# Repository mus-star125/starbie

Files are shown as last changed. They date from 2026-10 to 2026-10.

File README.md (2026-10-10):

# starbie

I made a starbie keychian - thats a bit vague. Basically a simpler version of the popular "starboy" keychain. its the first project we made in half-life and the first hardware - project I have ever made!

Before I even got to the instructions i ran into my first problem: downloading KiCad. Now this step is really easy on windows or mac but unfortunately I don't have those and had to use my chrome book. The process of downloading KiCad on Chromebook is different and was completely new to me. I had to start by installing Linux - which is a tiny computer in my computer- I assigned it about 10GB and had to code- download KiCad using terminal  - which is according to google: "a command-line interface application used to run text-based commands, access a Linux development environment, or perform system diagnostics."- After about an hour of trying to figure the code out i finally got it to install but then i realised 10GB was not enough so I moved it up to 25GB (That work wayy better)

**Some pics of me trying to figure linux and terminal out:**

Screenshot 2026-10-05 7 14 41 PM
Screenshot 2026-10-05 7 33 18 PM
Screenshot 2026-10-05 7 37 12 PM

for some reason it was a lot more tedious then it should have been. I think this process itself took me like 2 hours (which i wasn't able to count in my half life hours)  

Lessons learnt: **This wasn't as simple as I thought it would be** 
but i also learned that Linux was a mini computer system on mine and learned how to operate it :)

**CHALLENGE 2: Navigating KiCad**
I just could not understand the preferences and after downloading the "week one guide"zip I couldn't figure out how to put it onto KiCad, So my YouTube search started. I looked for videos and videos and ended up turning to slack, this was my last choice because I have a hard time turning for help since i enjoy figuring things out on my own and someone (i cant remember the @) sent a really helpful video which finally helped me understand it. So, i finally opened a schematic file and started searching for all the parts- honestly I'm still figuring out what each part does and how it all works but whatever info i find out Im going to add in here later.

I messed up again, I couldn't find the imported parts like the XIAO-ESP32-C3-SMD (which was the BRAIN of this project) at this point I was quite frustrated; whenever something seemed like it was going well another challenge came up... but I wasn't a quitter and by some playing around they appeared in my library (Again i had to share these files with Linux and it was making everything more difficult) but looking back at it I enjoy this process, when it all clicks all that frustration and hard work feels worth it!  

image0 (4)

I made my schematic file and I was soo proud of the result!
Schematic Edit: 



 I couldn't believe I the designed it all on my own (with the instructions and youtube <3). Finishing the schematic editor took me about 3.5 hours and I was really happy with the result!

**Making the PCB: Not as challenging as the Schematic :D**
I was really excited seeing my schematic becoming a model! It was kind of intimidating with the hundreds of tools in the PCB editor, but it ended up working out.

I started by organising my parts like the guide, i then went on the edge cut layer to make the star outline, this was probably the easiest part out of the project :) then i connected the wires. I was kind of worried because i did not have the same wiring as the guide, but with some research i realised that it will work the same. Then I added funny text and cute pictures on the board (Like the cute balloon dog). In all, the PCB was a much more enjoyable process than the schematic, but it still took me some time to get it done.About 6.5 hours in total. I finally downloaded the Gerber files and uploaded them onto my github

here is how it turned out: 

image1 (3)

**finally: The firmware**
The firmware was the quickest and easiest process out of the whole project; i used the beginner guide and made my own character. Making my sorite was difficult since i could only use black and white but I'm really proud with how it turned out. I have some things in mind that i want to experiment with but am waiting for the hardware for that.

This took me about 2 hours!

Then it occured to me that i wasn't a big fan of my star shape so I had to go back into the PCB editor to fix it, which was tedious because i had to re-download and re-upload my gerber files onto github and JLCPCB

Here is my Sprite:

sprite

Overall, this was a really enjoyable project and a good way to test my patience ;) It took me alot of time and my chromebook kept crashing out but I enjoyed it all and thank half-life for making this beginner friendly! I now have to figure out the funding and what to buy and how to make so I stay in the 30$

**week 1: SUCCESS!**

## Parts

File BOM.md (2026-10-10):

# Starbie – bill of materials

<!-- Generated by Half Life from project cmuvvz5y2026b01oscevl8rsv. Edits here are overwritten on the next sync. -->
<!-- Generated: 2026-10-10T16:02:22.605Z -->

> [!NOTE]
> This parts list is mirrored from [Half Life](https://halflife.hackclub.com). Editing it here will not change the platform's copy, and the next sync overwrites this file.

| Week | Tier | Parts funding |
| --- | --- | --- |
| Week 1 | Tier 1 | $30.00 |

| Part | What it's for | Qty | Unit | Total | Vendor |
| --- | --- | --- | --- | --- | --- |
| [PCB](https://cart.jlcpcb.com/shopcart/cart/) | holds electronic parts in place and connects them | 1 | $2.80 | $2.80 | [JLCPCB](https://cart.jlcpcb.com/shopcart/cart/) |
| [OLED Display](https://www.aliexpress.com/item/1005013248598840.html?mp=1) | where the action is going to happen | 1 | $3.87 | $3.87 | [AliExpress](https://www.aliexpress.com/item/1005013248598840.html?mp=1) |
| [Push buttons](https://www.aliexpress.com/item/1005006046180384.html?mp=1) | for changing option on the starbie | 1 | $4.46 | $4.46 | [AliExpress](https://www.aliexpress.com/item/1005006046180384.html?mp=1) |
| [PIn Header](https://www.aliexpress.com/item/1005007528068254.html?mp=1) | transmit data | 1 | $1.82 | $1.82 | [AliExpress](https://www.aliexpress.com/item/1005007528068254.html?mp=1) |
| **Parts subtotal** | — | — | — | **$12.95** | — |
| **Tax & shipping** | — | — | — | **$9.50** | — |
| **Total** | — | — | — | **$22.45** | — |

$7.55 left of the tier's funding.

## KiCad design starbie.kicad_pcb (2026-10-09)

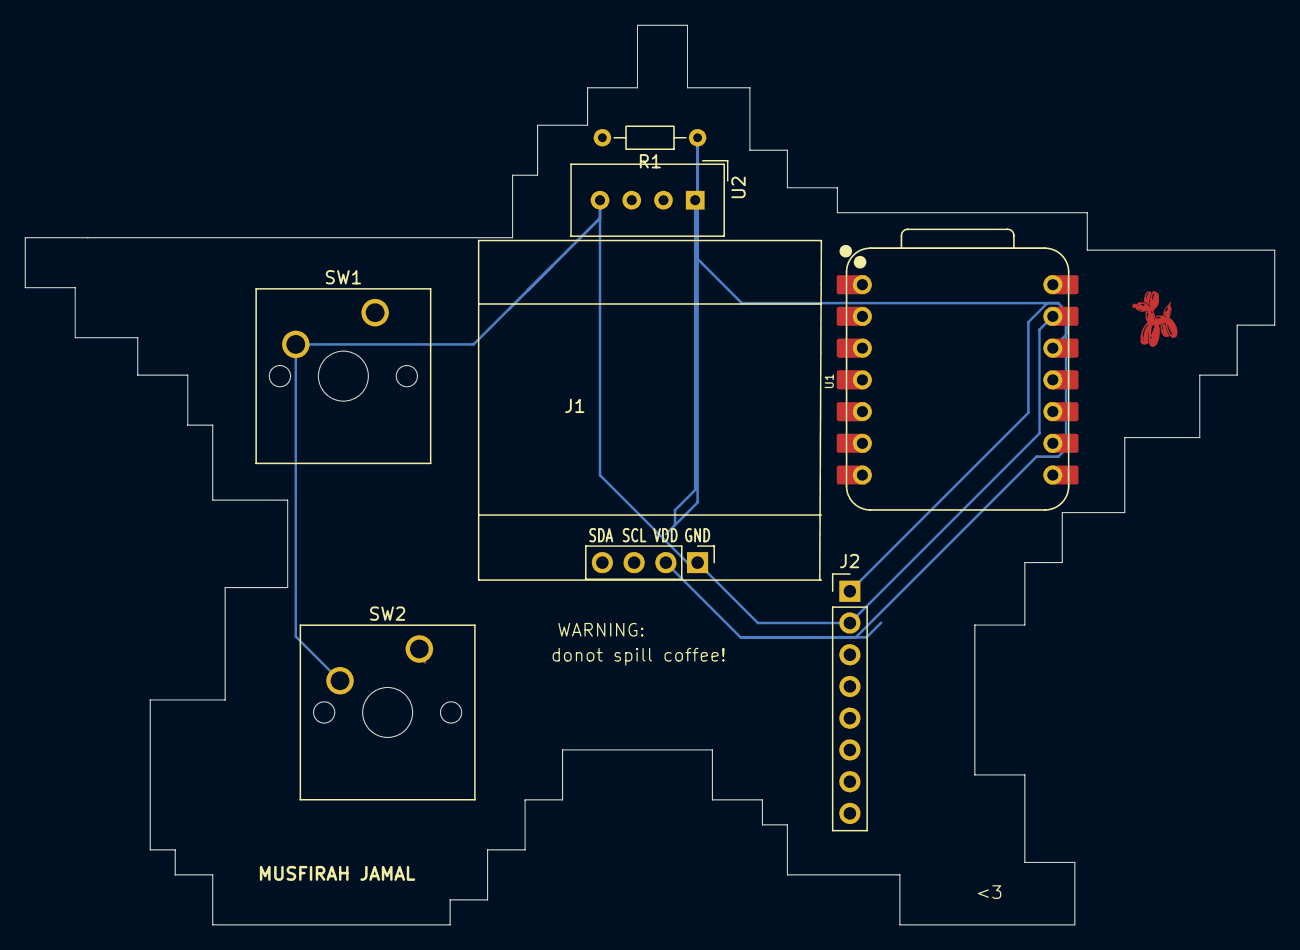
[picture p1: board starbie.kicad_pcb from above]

Board: 2 copper layers, 100.0 x 72.0 mm, 7 parts (0 on the bottom side), 2 nets.

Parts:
J1: Conn_01x04_Pin; Display_128x64_096_I2C
J2: Conn_01x08_Pin; PinHeader_1x08_P2.54mm_Vertical
R1: 10K; R_Axial_DIN0204_L3.6mm_D1.6mm_P7.62mm_Horizontal
SW1, SW2: SW_Push; SW_Cherry_MX_1.00u_PCB
U1: XIAO-ESP32-C3-SMD; XIAO-ESP32-C6-DIP
U2: DHT11; Aosong_DHT11_5.5x12.0_P2.54mm

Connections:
+3.3V: J1.2, J2.1, R1.1, U1.12 (3V3_OUT), U2.1 (VDD)
GND: J1.1, J2.2, SW1.2 (2_2), SW2.2 (2_2), U1.13 (GND), U2.4 (GND)

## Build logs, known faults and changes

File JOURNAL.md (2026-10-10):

# Starbie – devlog

<!-- Generated by Half Life from project cmuvvz5y2026b01oscevl8rsv. Edits here are overwritten on the next sync. -->
<!-- Generated: 2026-10-10T05:56:46.244Z -->

> [!NOTE]
> This devlog is mirrored from [Half Life](https://halflife.hackclub.com). Editing it here will not change the platform's copy, and the next sync overwrites this file.

> A tiny motion-controlled digital pet, basically a desktop Tamagotchi. Totally not a Starboy.

| Week | Tier | Hours logged | Entries |
| --- | --- | --- | --- |
| Week 1 | Tier 1 | 13.5h | 5 |

## Contents

1. [2026-10-06 – Today I struggled, I downloaded KiCad and got straight to work! I finished the Schimetic Editor file and this process took me about 3 h! this does not include the videos i watched and the millions of](#2026-10-06-today-i-struggled-i-downloaded-kicad-and-got-stra)
2. [2026-10-06 – Today was day 2 for hack club, and it was wayy easier then yesterday. I finished up my schematic editor and actually started the PCB, I enjoyed graphing the star but it was quite difficult I also move](#2026-10-06-today-was-day-2-for-hack-club-and-it-was-wayy-eas)
3. [2026-10-07 – today i wired, fixed the thousands of errors (started with 42) i had and added cute little stickers and photos on my pcb. safe to say I just need to add a few more details before im finally done. I sa](#2026-10-07-today-i-wired-fixed-the-thousands-of-errors-start)
4. [2026-10-08 – Today was a lighter day, i mostly spent today designing my PCB since im done (and did it wrong yesterday), and rechecking for errors I also learned how to use image converter which kinda confused me a](#2026-10-08-today-was-a-lighter-day-i-mostly-spent-today-desi)
5. [2026-10-10 – I finally finished up my project today. Im done with the firmware aswell! I really enjoyed making my sorite even though it took some time. the code was pretty easy since i used the beginner pack and j](#2026-10-10-i-finally-finished-up-my-project-today-im-done-wi)

## Design

### 2026-10-06 – Today I struggled, I downloaded KiCad and got straight to work! I finished the Schimetic Editor file and this process took me about 3 h! this does not include the videos i watched and the millions of

**3h**

Today I struggled, I downloaded KiCad and got straight to work! I finished the Schimetic Editor file and this process took me about 3 h! this does not include the videos i watched and the millions of websites i opened. My favoirtie part were the keyboard shortcuts, w for wire q for x ect







### 2026-10-06 – Today was day 2 for hack club, and it was wayy easier then yesterday. I finished up my schematic editor and actually started the PCB, I enjoyed graphing the star but it was quite difficult I also move

**2.5h**

Today was day 2 for hack club, and it was wayy easier then yesterday. I finished up my schematic editor and actually started the PCB, I enjoyed graphing the star but it was quite difficult I also moved some of the pieces around to match the guide



. I must say im really proud with how it turned out! Day 2, success!!



Screenshot 2026-10-06 8.34.33 PM

### 2026-10-07 – today i wired, fixed the thousands of errors (started with 42) i had and added cute little stickers and photos on my pcb. safe to say I just need to add a few more details before im finally done. I sa

**4h**

today i wired, fixed the thousands of errors (started with 42) i had and added cute little stickers and photos on my pcb. safe to say I just need to add a few more details before im finally done. I saw the 3D model and its so exciting seeing my work come to life!









### 2026-10-08 – Today was a lighter day, i mostly spent today designing my PCB since im done (and did it wrong yesterday), and rechecking for errors I also learned how to use image converter which kinda confused me a

**2h**

Today was a lighter day, i mostly spent today designing my PCB since im done (and did it wrong yesterday), and rechecking for errors I also learned how to use image converter which kinda confused me at first but by some playing around i got the hang of it!
Tonight im going to download arduine IDE, excited to start the firmware tomorrow!





### 2026-10-10 – I finally finished up my project today. Im done with the firmware aswell! I really enjoyed making my sorite even though it took some time. the code was pretty easy since i used the beginner pack and j

**2h**

I finally finished up my project today. Im done with the firmware aswell! I really enjoyed making my sorite even though it took some time. the code was pretty easy since i used the beginner pack and just had to make a few subtle changes. Overall good day!

sprite

Screenshot 2026-10-09 11.56.30 PM

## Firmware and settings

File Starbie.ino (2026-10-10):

#include <DNSServer.h>

#include <DNSServer.h>

/*
  Starbie: a tiny motion-controlled digital pet

  This is intentionally one file. Open this .ino file in Arduino IDE, edit
  the BEGINNER SETTINGS section, and upload it to a Seeed XIAO ESP32-C3.

  Install these libraries with Sketch > Include Library > Manage Libraries:
    - Adafruit GFX Library
    - Adafruit SSD1306
    - Adafruit MPU6050
    - DHT sensor library
  Arduino IDE will offer to install their dependencies too. Click Install All.
*/

#include <Wire.h>
#include <Adafruit_GFX.h>
#include <Adafruit_SSD1306.h>
#include <Adafruit_MPU6050.h>
#include <DHT.h>
#include <Preferences.h>
#include <math.h>

// =========================== BEGINNER SETTINGS ===========================
// Everything most builders will want to customize is in this one section.

// --- Your board's pins ----------------------------------------------------
// These are ESP32-C3 GPIO numbers, with the XIAO pin labels beside them.
const int I2C_SDA_PIN = 5;       // XIAO D5: OLED + MPU6050 SDA
const int I2C_SCL_PIN = 6;       // XIAO D6: OLED + MPU6050 SCL
const int DHT_PIN = 2;           // XIAO D2: DHT11 data
const int BUTTON_ONE_PIN = 3;    // XIAO D3: opens/confirms the radial menu
const int BUTTON_TWO_PIN = 4;    // XIAO D4: shows/hides stats

// Set this to false if your submission does not have a DHT11.
const bool USE_DHT11 = true;

// Most parts use these addresses. Only change them if an I2C scanner says
// your part is different (common OLED alternative: 0x3D).
const uint8_t OLED_ADDRESS = 0x3C;
const uint8_t MPU6050_ADDRESS = 0x68;

// --- Starting stats -------------------------------------------------------
// Stats are 0 to 100. They only change when you select an action or shake
// Starbie; nothing slowly drains while it sits on your desk.
const int STARTING_JOY = 70;
const int STARTING_ENERGY = 75;
const int STARTING_FULLNESS = 65;

// Set true, upload once, then set it back to false if you want a fresh pet.
const bool RESET_SAVED_PET_ON_BOOT = false;

// --- Radial menu ----------------------------------------------------------
// These four actions appear at TOP, RIGHT, BOTTOM, then LEFT in the menu.
// The last word controls the matching little visual reaction.
enum PetReaction {
  NAP_REACTION,
  JUMP_REACTION,
  HEART_REACTION,
  RUN_REACTION,
};

struct MenuItem {
  const char *label;
  int joyChange;
  int energyChange;
  int fullnessChange;
  PetReaction reaction;
};

const MenuItem MENU_ITEMS[] = {
  {"NAP",   1,  18, -4, NAP_REACTION},   // top: sleep and emit Zs
  {"PLAY", 12, -9, -5, RUN_REACTION},    // right: two fast laps + hearts
  {"FEED",  3,  2,  18, JUMP_REACTION},  // bottom: wiggle and jump
  {"PET",   7,  0,  0, HEART_REACTION},  // left: jump and emit hearts
};
const int MENU_ITEM_COUNT = sizeof(MENU_ITEMS) / sizeof(MENU_ITEMS[0]);

// --- Movement feel --------------------------------------------------------
// Bigger MENU_TILT_LIMIT makes the menu ball move less.
const float MENU_TILT_LIMIT = 6.0f;

// MPU6050 orientation: change these settings instead of rewiring your board.
// 1. If the sensor is turned 90 degrees, set SWAP_MPU_AXES to true.
// 2. If a direction feels backwards, change that direction from 1.0f to -1.0f.
const bool SWAP_MPU_AXES = false;
const float MENU_X_DIRECTION = 1.0f;
const float MENU_Y_DIRECTION = -1.0f;

// A small dead zone makes the ball rest in the center until the board is tilted.
const float MENU_CENTER_DEADZONE = 0.8f;
const float SHAKE_THRESHOLD = 7.0f;

// Shake is the only movement that has an effect outside the radial menu.
const int SHAKE_JOY_CHANGE = 5;
const int SHAKE_ENERGY_CHANGE = -2;
const int SHAKE_FULLNESS_CHANGE = -1;

// --- Your pet's bitmap and animation -------------------------------------
// This is a simplified 32 by 32, one-bit version of the supplied character.
// You can replace it with your own art later; keep these size values matched
// to the sprite array you paste in.
const int PET_SPRITE_WIDTH = 32;
const int PET_SPRITE_HEIGHT = 32;

// The pet wanders unless it is asleep. A non-nap action does a tiny shake,
// then a jump, except PLAY which runs two fast laps.
const uint16_t PET_WALK_PIXEL_MS = 70;
const uint16_t PET_PRE_JUMP_MS = 230;
const uint16_t PET_JUMP_MS = 430;
const int PET_JUMP_HEIGHT = 16;
const uint32_t NAP_DURATION_MS = 48000;  // 48 seconds: four times the old nap.
const uint16_t HEARTS_DURATION_MS = 1600;
const uint16_t PLAY_LAP_MS = 800;
const uint8_t PLAY_LAP_COUNT = 2;

// Each byte stores eight pixels, left to right. This sparse outline keeps the
// supplied creature readable on a tiny, one-bit OLED: head, eye, legs, tail,
// and a small flower-like ear accent all stay separate instead of becoming a blob.
const int PET_SPRITE_WIDTH = 32;
const int PET_SPRITE_HEIGHT = 32;

const uint8_t PROGMEM PET_SPRITE[] = {
  0x00, 0x00, 0x00, 0x00, 0x00, 0x00, 0x00, 0x00, 0x00, 0x00, 0x00, 0x00, 0x00, 0x00, 0x00, 0x00, 
  0x00, 0x00, 0x00, 0x00, 0x00, 0x00, 0x00, 0x00, 0x00, 0x07, 0xc0, 0x00, 0x00, 0x18, 0x30, 0x00, 
  0x00, 0x30, 0x0c, 0x00, 0x00, 0x40, 0x02, 0x00, 0x00, 0x88, 0x21, 0x00, 0x01, 0x14, 0x50, 0x80, 
  0x01, 0x08, 0x20, 0x80, 0x02, 0x00, 0x00, 0x40, 0x02, 0x04, 0x40, 0x40, 0x01, 0x03, 0x80, 0x80, 
  0x01, 0x00, 0x00, 0x80, 0x00, 0x92, 0x49, 0x00, 0x00, 0x6d, 0xb6, 0x00, 0x00, 0x44, 0x22, 0x00, 
  0x00, 0x82, 0x22, 0x00, 0x00, 0x42, 0x11, 0x00, 0x00, 0x44, 0x11, 0x00, 0x00, 0x44, 0x22, 0x00, 
  0x00, 0x82, 0x12, 0x00, 0x00, 0x84, 0x21, 0x00, 0x00, 0x44, 0x22, 0x00, 0x00, 0x44, 0x11, 0x00, 
  0x00, 0x82, 0x12, 0x00, 0x00, 0x00, 0x00, 0x00, 0x00, 0x00, 0x00, 0x00, 0x00, 0x00, 0x00, 0x00
};
// ===========================================================================
// You can read below without needing to understand every line. The rest of
// the sketch handles buttons, sensors, drawing, and saving automatically.

const int SCREEN_WIDTH = 128;
const int SCREEN_HEIGHT = 64;
const int MENU_CENTER_X = 64;
const int MENU_CENTER_Y = 32;
const int MENU_ITEM_X[] = {64, 108, 64, 20};
const int MENU_ITEM_Y[] = {12, 32, 53, 32};
const int MENU_BALL_X_RANGE = 37;
const int MENU_BALL_Y_RANGE = 22;
const uint16_t BUTTON_DEBOUNCE_MS = 30;
const uint16_t MPU_READ_INTERVAL_MS = 30;
const uint16_t DHT_READ_INTERVAL_MS = 2200;
const uint16_t SHAKE_COOLDOWN_MS = 650;
const float STANDARD_GRAVITY = 9.80665f;

Adafruit_SSD1306 display(SCREEN_WIDTH, SCREEN_HEIGHT, &Wire, -1);
Adafruit_MPU6050 mpu;
DHT dht(DHT_PIN, DHT11);
Preferences preferences;

struct PetState {
  int joy;
  int energy;
  int fullness;
};

struct ButtonState {
  int pin;
  bool stableState;
  bool lastRawState;
  uint32_t lastChangedAt;
};

enum View {
  PET_VIEW,
  MENU_VIEW,
  STATS_VIEW,
};

PetState pet = {STARTING_JOY, STARTING_ENERGY, STARTING_FULLNESS};
ButtonState buttonOne = {BUTTON_ONE_PIN, HIGH, HIGH, 0};
ButtonState buttonTwo = {BUTTON_TWO_PIN, HIGH, HIGH, 0};
View currentView = PET_VIEW;

bool mpuFound = false;
bool dhtFound = false;
float accelerationX = 0.0f;
float accelerationY = 0.0f;
float accelerationZ = STANDARD_GRAVITY;
float temperatureC = NAN;
float humidity = NAN;
float menuBallX = MENU_CENTER_X;
float menuBallY = MENU_CENTER_Y;
float menuCenterAccelerationX = 0.0f;
float menuCenterAccelerationY = 0.0f;
int selectedMenuItem = -1;
uint32_t lastMpuReadAt = 0;
uint32_t lastDhtReadAt = 0;
uint32_t lastShakeAt = 0;
uint32_t shakeAnimationEndsAt = 0;
uint32_t petJumpStartedAt = 0;
uint32_t nappingUntil = 0;
uint32_t heartAnimationEndsAt = 0;
uint32_t playRunStartedAt = 0;
int nappingPetX = 0;

int petWalkingX(uint32_t now);

int keepInRange(int value, int smallest, int largest) {
  return constrain(value, smallest, largest);
}

void changePet(int joyChange, int energyChange, int fullnessChange) {
  pet.joy = keepInRange(pet.joy + joyChange, 0, 100);
  pet.energy = keepInRange(pet.energy + energyChange, 0, 100);
  pet.fullness = keepInRange(pet.fullness + fullnessChange, 0, 100);
}

void loadPet() {
  preferences.begin("starbie", false);
  if (RESET_SAVED_PET_ON_BOOT) {
    preferences.clear();
  }
  pet.joy = preferences.getInt("joy", STARTING_JOY);
  pet.energy = preferences.getInt("energy", STARTING_ENERGY);
  pet.fullness = preferences.getInt("full", STARTING_FULLNESS);
}

void savePet() {
  preferences.putInt("joy", pet.joy);
  preferences.putInt("energy", pet.energy);
  preferences.putInt("full", pet.fullness);
}

void setUpButton(ButtonState &button) {
  pinMode(button.pin, INPUT_PULLUP);
  button.stableState = digitalRead(button.pin);
  button.lastRawState = button.stableState;
  button.lastChangedAt = millis();
}

// Returns true exactly once for each press, even if the switch bounces.
bool wasPressed(ButtonState &button) {
  const bool rawState = digitalRead(button.pin);
  const uint32_t now = millis();

  if (rawState != button.lastRawState) {
    button.lastRawState = rawState;
    button.lastChangedAt = now;
  }

  if (rawState != button.stableState &&
      now - button.lastChangedAt >= BUTTON_DEBOUNCE_MS) {
    button.stableState = rawState;
    return button.stableState == LOW;
  }

  return false;
}

void updateMpu() {
  if (!mpuFound || millis() - lastMpuReadAt < MPU_READ_INTERVAL_MS) {
    return;
  }
  lastMpuReadAt = millis();

  sensors_event_t acceleration;
  sensors_event_t gyro;
  sensors_event_t sensorTemperature;
  mpu.getEvent(&acceleration, &gyro, &sensorTemperature);
  accelerationX = acceleration.acceleration.x;
  accelerationY = acceleration.acceleration.y;
  accelerationZ = acceleration.acceleration.z;
}

void updateDht() {
  if (!dhtFound || millis() - lastDhtReadAt < DHT_READ_INTERVAL_MS) {
    return;
  }
  lastDhtReadAt = millis();

  const float newHumidity = dht.readHumidity();
  const float newTemperatureC = dht.readTemperature();
  if (!isnan(newHumidity)) {
    humidity = newHumidity;
  }
  if (!isnan(newTemperatureC)) {
    temperatureC = newTemperatureC;
  }
}

int petWalkingX(uint32_t now) {
  const int farthestX = SCREEN_WIDTH - PET_SPRITE_WIDTH;
  const uint32_t roundTrip = static_cast<uint32_t>(farthestX) * 2;
  const uint32_t step = (now / PET_WALK_PIXEL_MS) % roundTrip;
  return step <= farthestX ? step : roundTrip - step;
}

uint32_t playRunDuration() {
  return static_cast<uint32_t>(PLAY_LAP_MS) * PLAY_LAP_COUNT;
}

bool isNapping() {
  return nappingUntil != 0 && millis() < nappingUntil;
}

bool isPlaying() {
  return playRunStartedAt != 0 && millis() - playRunStartedAt < playRunDuration();
}

int playRunX(uint32_t now) {
  const int farthestX = SCREEN_WIDTH - PET_SPRITE_WIDTH;
  const uint32_t lapAge = (now - playRunStartedAt) % PLAY_LAP_MS;
  const float progress = static_cast<float>(lapAge) / PLAY_LAP_MS;
  return progress < 0.5f ? static_cast<int>(progress * 2.0f * farthestX)
                         : static_cast<int>((1.0f - progress) * 2.0f * farthestX);
}

void updatePetTimers() {
  if (nappingUntil != 0 && !isNapping()) {
    nappingUntil = 0;  // The pet wakes naturally when its nap time is over.
  }
  if (playRunStartedAt != 0 && !isPlaying()) {
    playRunStartedAt = 0;  // PLAY is exactly two left-to-right-to-left laps.
  }
}

// While the menu is open, the MPU6050 acts like a tiny air mouse. The position
// at the instant Button 1 opens the menu becomes the center for that menu use.
void updateMenuBall() {
  float xTilt = accelerationX - menuCenterAccelerationX;
  float yTilt = accelerationY - menuCenterAccelerationY;

  if (SWAP_MPU_AXES) {
    const float oldXTilt = xTilt;
    xTilt = yTilt;
    yTilt = oldXTilt;
  }
  xTilt = constrain(xTilt * MENU_X_DIRECTION, -MENU_TILT_LIMIT, MENU_TILT_LIMIT);
  yTilt = constrain(yTilt * MENU_Y_DIRECTION, -MENU_TILT_LIMIT, MENU_TILT_LIMIT);
  const float targetX = MENU_CENTER_X + (xTilt / MENU_TILT_LIMIT) * MENU_BALL_X_RANGE;
  const float targetY = MENU_CENTER_Y + (yTilt / MENU_TILT_LIMIT) * MENU_BALL_Y_RANGE;

  // This small amount of smoothing makes the ball feel less jittery.
  menuBallX += (targetX - menuBallX) * 0.20f;
  menuBallY += (targetY - menuBallY) * 0.20f;

  // The menu has four full sectors, not four tiny targets. Any tilt direction
  // past the center dead zone selects its matching top/right/bottom/left action.
  if (fabsf(xTilt) < MENU_CENTER_DEADZONE && fabsf(yTilt) < MENU_CENTER_DEADZONE) {
    selectedMenuItem = -1;
  } else if (fabsf(xTilt) > fabsf(yTilt)) {
    selectedMenuItem = xTilt > 0.0f ? 1 : 3;  // right or left
  } else {
    selectedMenuItem = yTilt > 0.0f ? 2 : 0;  // bottom or top
  }
}

void checkForShake() {
  if (!mpuFound || currentView != PET_VIEW) {
    return;
  }

  const float magnitude = sqrtf(accelerationX * accelerationX +
                                accelerationY * accelerationY +
                                accelerationZ * accelerationZ);
  const uint32_t now = millis();
  if (fabsf(magnitude - STANDARD_GRAVITY) >= SHAKE_THRESHOLD &&
      now - lastShakeAt >= SHAKE_COOLDOWN_MS) {
    lastShakeAt = now;
    nappingUntil = 0;  // A shake wakes a sleeping pet right away.
    shakeAnimationEndsAt = now + 350;
    changePet(SHAKE_JOY_CHANGE, SHAKE_ENERGY_CHANGE, SHAKE_FULLNESS_CHANGE);
    savePet();
  }
}

void openMenu() {
  currentView = MENU_VIEW;
  selectedMenuItem = -1;
  menuBallX = MENU_CENTER_X;
  menuBallY = MENU_CENTER_Y;
  // Calibrate here so every menu starts from however the builder is holding it.
  menuCenterAccelerationX = accelerationX;
  menuCenterAccelerationY = accelerationY;
}

void chooseMenuItem() {
  if (selectedMenuItem == -1) {
    return;  // Keep the menu open until the ball reaches a choice.
  }

  const MenuItem &item = MENU_ITEMS[selectedMenuItem];
  changePet(item.joyChange, item.energyChange, item.fullnessChange);
  savePet();
  const uint32_t now = millis();
  nappingUntil = 0;
  heartAnimationEndsAt = 0;
  playRunStartedAt = 0;

  if (item.reaction == NAP_REACTION) {
    petJumpStartedAt = 0;
    nappingPetX = petWalkingX(now);
    nappingUntil = now + NAP_DURATION_MS;
  } else if (item.reaction == RUN_REACTION) {
    petJumpStartedAt = 0;
    playRunStartedAt = now;
    heartAnimationEndsAt = now + playRunDuration();
  } else {
    // A confirmed action gets a little anticipation shake before the jump.
    petJumpStartedAt = now;
    if (item.reaction == HEART_REACTION) {
      heartAnimationEndsAt = now + HEARTS_DURATION_MS;
    }
  }
  currentView = PET_VIEW;
}

void handleButtons() {
  if (wasPressed(buttonOne)) {
    if (currentView == MENU_VIEW) {
      chooseMenuItem();
    } else {
      openMenu();
    }
  }

  if (wasPressed(buttonTwo)) {
    // Button 2 never changes the pet. It only lets you peek at the values.
    currentView = currentView == STATS_VIEW ? PET_VIEW : STATS_VIEW;
  }
}
void drawSparkle(int x, int y) {
  display.drawPixel(x, y - 2, SSD1306_WHITE);
  display.drawPixel(x - 1, y - 1, SSD1306_WHITE);
  display.drawPixel(x + 1, y - 1, SSD1306_WHITE);
  display.drawPixel(x - 2, y, SSD1306_WHITE);
  display.drawPixel(x, y, SSD1306_WHITE);
  display.drawPixel(x + 2, y, SSD1306_WHITE);
  display.drawPixel(x - 1, y + 1, SSD1306_WHITE);
  display.drawPixel(x + 1, y + 1, SSD1306_WHITE);
  display.drawPixel(x, y + 2, SSD1306_WHITE);
}

void drawHeart(int x, int y) {
  // A tiny seven-pixel-wide heart that stays crisp on the OLED.
  display.fillRect(x - 2, y, 2, 2, SSD1306_WHITE);
  display.fillRect(x + 1, y, 2, 2, SSD1306_WHITE);
  display.fillRect(x - 3, y + 2, 7, 2, SSD1306_WHITE);
  display.fillRect(x - 2, y + 4, 5, 1, SSD1306_WHITE);
  display.fillRect(x - 1, y + 5, 3, 1, SSD1306_WHITE);
  display.drawPixel(x, y + 6, SSD1306_WHITE);
}

void drawHearts(uint32_t now, int petX, int petY) {
  if (now >= heartAnimationEndsAt) {
    return;
  }

  const float progress =
      1.0f - static_cast<float>(heartAnimationEndsAt - now) / HEARTS_DURATION_MS;
  const int rise = static_cast<int>(progress * 18.0f);
  drawHeart(petX + 10, petY - 3 - rise);
  drawHeart(petX + 22, petY - 9 - rise / 2);
}

void drawSleepZs(uint32_t now, int petX, int petY) {
  // The Zs float upward, then loop back down while the pet is napping.
  const int rise = static_cast<int>((now / 300UL) % 15UL);
  display.setTextSize(1);
  display.setTextColor(SSD1306_WHITE);
  display.setCursor(petX + 23, petY - 2 - rise);
  display.print("z");
  display.setCursor(petX + 28, petY - 8 - rise / 2);
  display.print("z");
}

void drawPet() {
  display.clearDisplay();

  const uint32_t now = millis();
  int petX = isNapping() ? nappingPetX : petWalkingX(now);
  if (isPlaying()) {
    petX = playRunX(now);
  }
  int petY = SCREEN_HEIGHT - PET_SPRITE_HEIGHT;

  // The pet always wanders except during a nap; PLAY temporarily takes over.
  if (now < shakeAnimationEndsAt) {
    petX += static_cast<int>(sinf(now / 18.0f) * 3.0f);
  }

  if (!isNapping() && petJumpStartedAt != 0) {
    const uint32_t animationAge = now - petJumpStartedAt;

    if (animationAge < PET_PRE_JUMP_MS) {
      petX += static_cast<int>(sinf(now / 16.0f) * 3.0f);
    } else if (animationAge < PET_PRE_JUMP_MS + PET_JUMP_MS) {
      const float jumpProgress =
          static_cast<float>(animationAge - PET_PRE_JUMP_MS) / PET_JUMP_MS;
      petY -= static_cast<int>(sinf(jumpProgress * PI) * PET_JUMP_HEIGHT);
    } else {
      petJumpStartedAt = 0;
    }
  }

  petX = constrain(petX, 0, SCREEN_WIDTH - PET_SPRITE_WIDTH);
  display.drawBitmap(petX, petY, PET_SPRITE, PET_SPRITE_WIDTH, PET_SPRITE_HEIGHT,
                     SSD1306_WHITE);
                     
  if (!isNapping() && (now / 250) % 2 == 0) {
  drawSparkle(petX - 4, petY + 18);
}

  if (isNapping()) {
    drawSleepZs(now, petX, petY);
  }
  drawHearts(now, petX, petY);
}

void drawMenuItem(int item) {
  const int boxWidth = 33;
  const int boxHeight = 12;
  const int boxX = MENU_ITEM_X[item] - boxWidth / 2;
  const int boxY = MENU_ITEM_Y[item] - boxHeight / 2;
  const bool isSelected = item == selectedMenuItem;

  if (isSelected) {
    display.fillRoundRect(boxX, boxY, boxWidth, boxHeight, 3, SSD1306_WHITE);
    display.setTextColor(SSD1306_BLACK);
  } else {
    display.drawRoundRect(boxX, boxY, boxWidth, boxHeight, 3, SSD1306_WHITE);
    display.setTextColor(SSD1306_WHITE);
  }

  display.setTextSize(1);
  const int labelLength = strlen(MENU_ITEMS[item].label);
  display.setCursor(MENU_ITEM_X[item] - labelLength * 3, MENU_ITEM_Y[item] - 3);
  display.print(MENU_ITEMS[item].label);
  display.setTextColor(SSD1306_WHITE);
}

void drawMenu() {
  display.clearDisplay();
  // The two diagonal lines divide the screen into four big selection sectors.
  display.drawLine(0, 0, SCREEN_WIDTH - 1, SCREEN_HEIGHT - 1, SSD1306_WHITE);
  display.drawLine(0, SCREEN_HEIGHT - 1, SCREEN_WIDTH - 1, 0, SSD1306_WHITE);
  for (int item = 0; item < MENU_ITEM_COUNT; item++) {
    drawMenuItem(item);
  }

  display.drawCircle(MENU_CENTER_X, MENU_CENTER_Y, 11, SSD1306_WHITE);
  display.fillCircle(static_cast<int>(menuBallX), static_cast<int>(menuBallY), 4,
                     SSD1306_WHITE);
}

void drawStatBar(int y, const char *label, int value) {
  display.setTextSize(1);
  display.setTextColor(SSD1306_WHITE);
  display.setCursor(4, y);
  display.print(label);
  display.drawRect(48, y, 57, 8, SSD1306_WHITE);
  display.fillRect(49, y + 1, map(value, 0, 100, 0, 55), 6, SSD1306_WHITE);
  display.setCursor(109, y);
  display.print(value);
}

void drawStats() {
  display.clearDisplay();
  drawStatBar(5, "JOY", pet.joy);
  drawStatBar(20, "ENERGY", pet.energy);
  drawStatBar(35, "FULL", pet.fullness);

  display.setCursor(4, 53);
  if (!isnan(temperatureC)) {
    display.print("TEMP ");
    display.print(static_cast<int>(temperatureC));
    display.print("C");
  } else {
    display.print("TEMP --");
  }

  display.setCursor(76, 53);
  if (!isnan(humidity)) {
    display.print("H ");
    display.print(static_cast<int>(humidity));
    display.print("%");
  } else {
    display.print("H --");
  }
}

void drawCurrentView() {
  if (currentView == MENU_VIEW) {
    drawMenu();
  } else if (currentView == STATS_VIEW) {
    drawStats();
  } else {
    drawPet();
  }
  display.display();
}

void setup() {
  Serial.begin(115200);
  Wire.begin(I2C_SDA_PIN, I2C_SCL_PIN);
  setUpButton(buttonOne);
  setUpButton(buttonTwo);
  loadPet();

  if (!display.begin(SSD1306_SWITCHCAPVCC, OLED_ADDRESS)) {
    Serial.println("OLED not found. Check power, GND, SDA, SCL, and address.");
    while (true) {
      delay(10);
    }
  }

  mpuFound = mpu.begin(MPU6050_ADDRESS, &Wire);
  if (mpuFound) {
    mpu.setAccelerometerRange(MPU6050_RANGE_8_G);
    mpu.setGyroRange(MPU6050_RANGE_500_DEG);
    mpu.setFilterBandwidth(MPU6050_BAND_21_HZ);
  } else {
    Serial.println("MPU6050 not found. The menu will not move until it is connected.");
  }

  if (USE_DHT11) {
    dht.begin();
    dhtFound = true;
  }

  drawCurrentView();
}

void loop() {
  updateMpu();
  updateDht();
  updatePetTimers();
  handleButtons();

  if (currentView == MENU_VIEW) {
    updateMenuBall();
  } else {
    checkForShake();
  }

  drawCurrentView();
  delay(16);  // Smooth display updates without making the code complicated.
}

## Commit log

2026-10-06 Log hours and add entry for October 6th
    Updated journal entry for Week 1 with hours logged and added a new entry for October 6th detailing progress on KiCad.
2026-10-08 Enhance README with project journey and lessons learned
    Expanded the README with detailed project experiences and challenges faced while using KiCad and Linux.
2026-10-10 Update README with project insights and images
    Added detailed project experience and reflections on PCB design and firmware development.
2026-10-18 Add BOM entries for components and pricing
2026-10-21 Revise README with project challenges and updates
    Updated README to include detailed devlogs for challenges faced while creating the starbie keychain project, including downloading KiCad, navigating the schematic editor, making the PCB, and writing 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
2026-10-22 Add Bill of Materials section to README
    Added a Bill of Materials (BOM) section with component details and costs.
2026-10-22 Fix image source and enhance PCB explanation
    Updated image link in README and revised PCB description.
2026-10-26 Document challenges faced during KiCad project
    Added detailed challenges and experiences related to using KiCad, firmware writing, and PCB design. Included time spent and lessons learned for each challenge.
2026-10-26 Fix duplicate feature entries in README
    Removed duplicate entries for custom jellyfish sprite, OLED display, RGB LED, custom star-shaped PCB, and custom firmware in the features section.
2026-10-31 Update BOM with new components and remove old entries
2026-10-31 Add MPU6050 module to BOM
2026-10-31 Fix description of MPU6050 accelerometer
2026-10-31 Add MPU6050 accelerometer to parts list
2026-10-31 Revise BOM format with pricing and vendor details
    Updated the Bill of Materials (BOM) format to include pricing and vendor links.
2026-10-31 Revise BOM with pricing and vendor details
    Updated the Bill of Materials (BOM) section to include detailed pricing and vendor information for components.
